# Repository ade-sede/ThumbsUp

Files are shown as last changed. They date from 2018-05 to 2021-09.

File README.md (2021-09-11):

# ThumbsUp !

A hand-worn wireless mouse made by four software developer students at school 42 Paris.
This was our free project to complete the electronics development course at 42's electronic lab.
In the traditional spirit of 42, no external libraries are allowed:
- schematic and footprints libraries were designed from scratch.
- firmware is bare metal working up from CMSIS headers.

## Main hardware components
- [RN42HID Bluetooth 2.1 Module](https://www.microchip.com/wwwproducts/en/RN42)
- [MPU9150 9-DoF sensor](https://www.olimex.com/Products/Modules/Sensors/MOD-MPU9150/open-source-hardware)
- [PIC32MX](https://lmgtfy.com/?q=PIC32+MX+Family)

A BOM is available in the `output_files/BOM` directory.

## Development tools
Altium and MPLAB IDE(xc32 compiler)

## Result
Turned out to be pretty cool and fully functional.

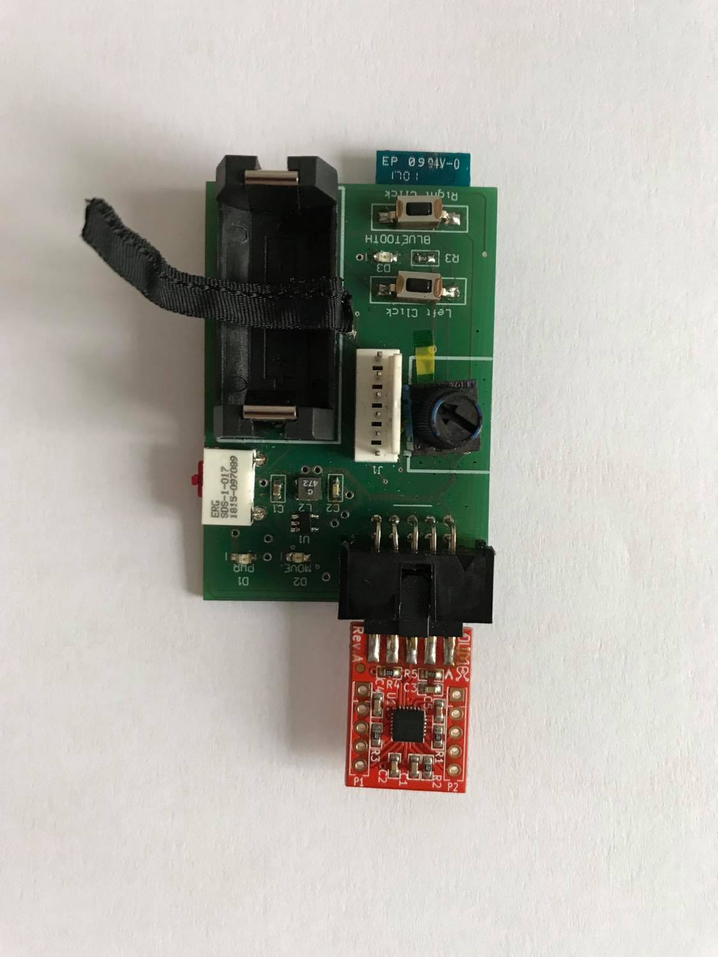
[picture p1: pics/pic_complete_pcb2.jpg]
RAW PCBA

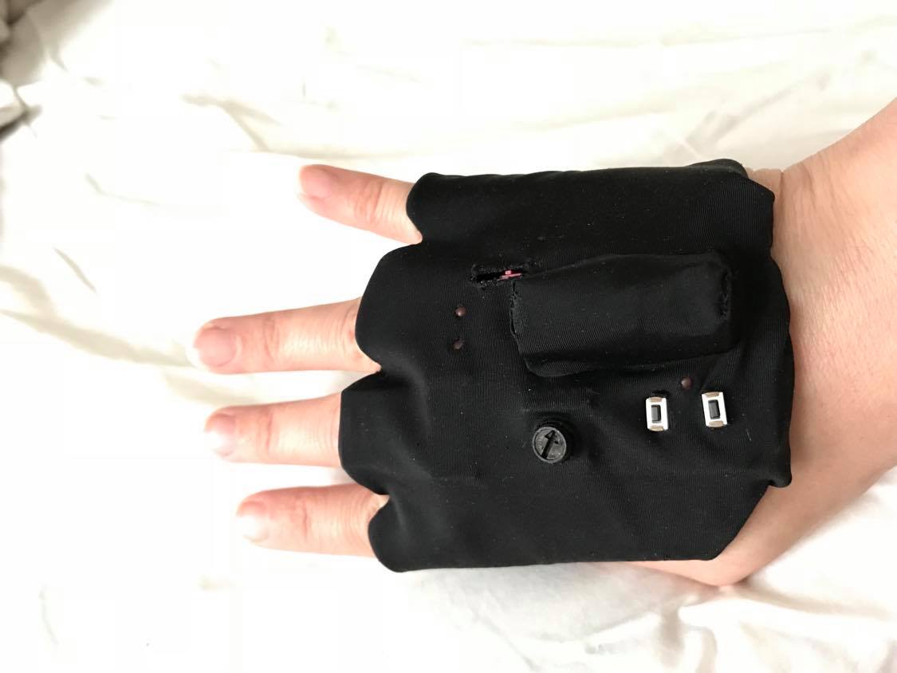
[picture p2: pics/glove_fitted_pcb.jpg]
Fitted in a glove


# Authors
- [ade-sede](https://github.com/ade-sede)
- [ssabbah](https://github.com/solalsabbah)
- [asuissa](https://github.com/asuissa)
- [alallema](https://github.com/alallema)

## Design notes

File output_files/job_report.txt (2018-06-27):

Output: Bill of Materials
Type  : BOM
From  : Variant [[No Variations]] of Project [ThumbsUp.PrjPcb]
   Generated File[Bill of Materials-ThumbsUp.xlsx]

Files Generated   : 1
Documents Printed : 0

Finished Output Generation At 4:39:21 AM On 6/27/2018

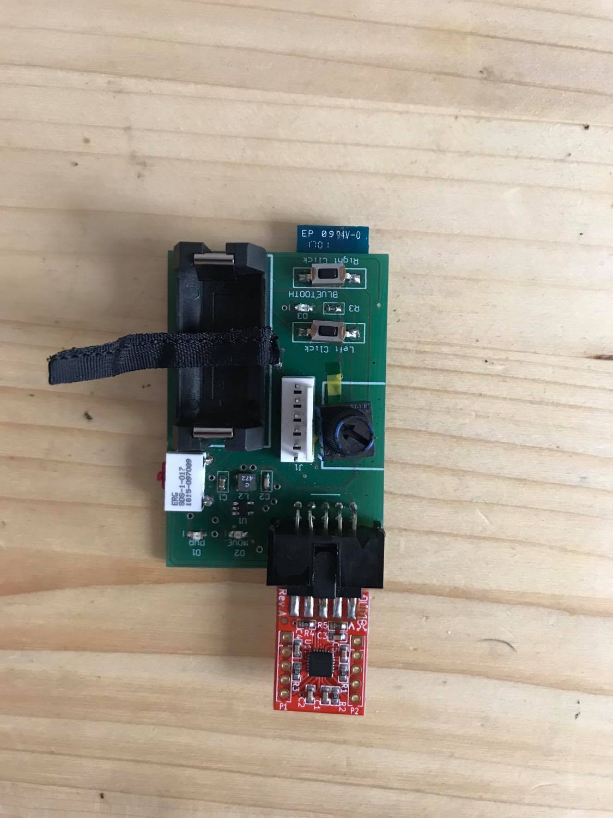
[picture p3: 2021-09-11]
pics/pic_complete_pcb1.jpg

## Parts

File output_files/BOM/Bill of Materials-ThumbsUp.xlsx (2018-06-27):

Quantity | LogicalDesignator | Fabricant | Fournisseur | RefFabricant | RefFournisseur
1 | BT2 | Keystone | Farnell | 1017 | 1888395
5 | D1, D2, D3 | Kingbright | Farnell | KPT-2012LVSECK-J3-PRV | 2610416
10 | J1 | MOLEX | Farnell | 22-27-2061 | 9731172
1 | L2 | Coilcraft | Farnell | XFL3012-472MEB | 2289189
1 | SW1 | ERG COMPONENTS | Farnell | SDS-1-017 | 1203424
10 | SW2 | ALCOSWITCH - TE CONNECTIVITY | Farnell | 1437566-3 | 2468741
1 | U1 | Microchip | Farnell | MCP1603T-330I/OS | 1439373
1 | U2 | Microchip | Farnell | PIC32MX150F128B-I/SO | 2313766

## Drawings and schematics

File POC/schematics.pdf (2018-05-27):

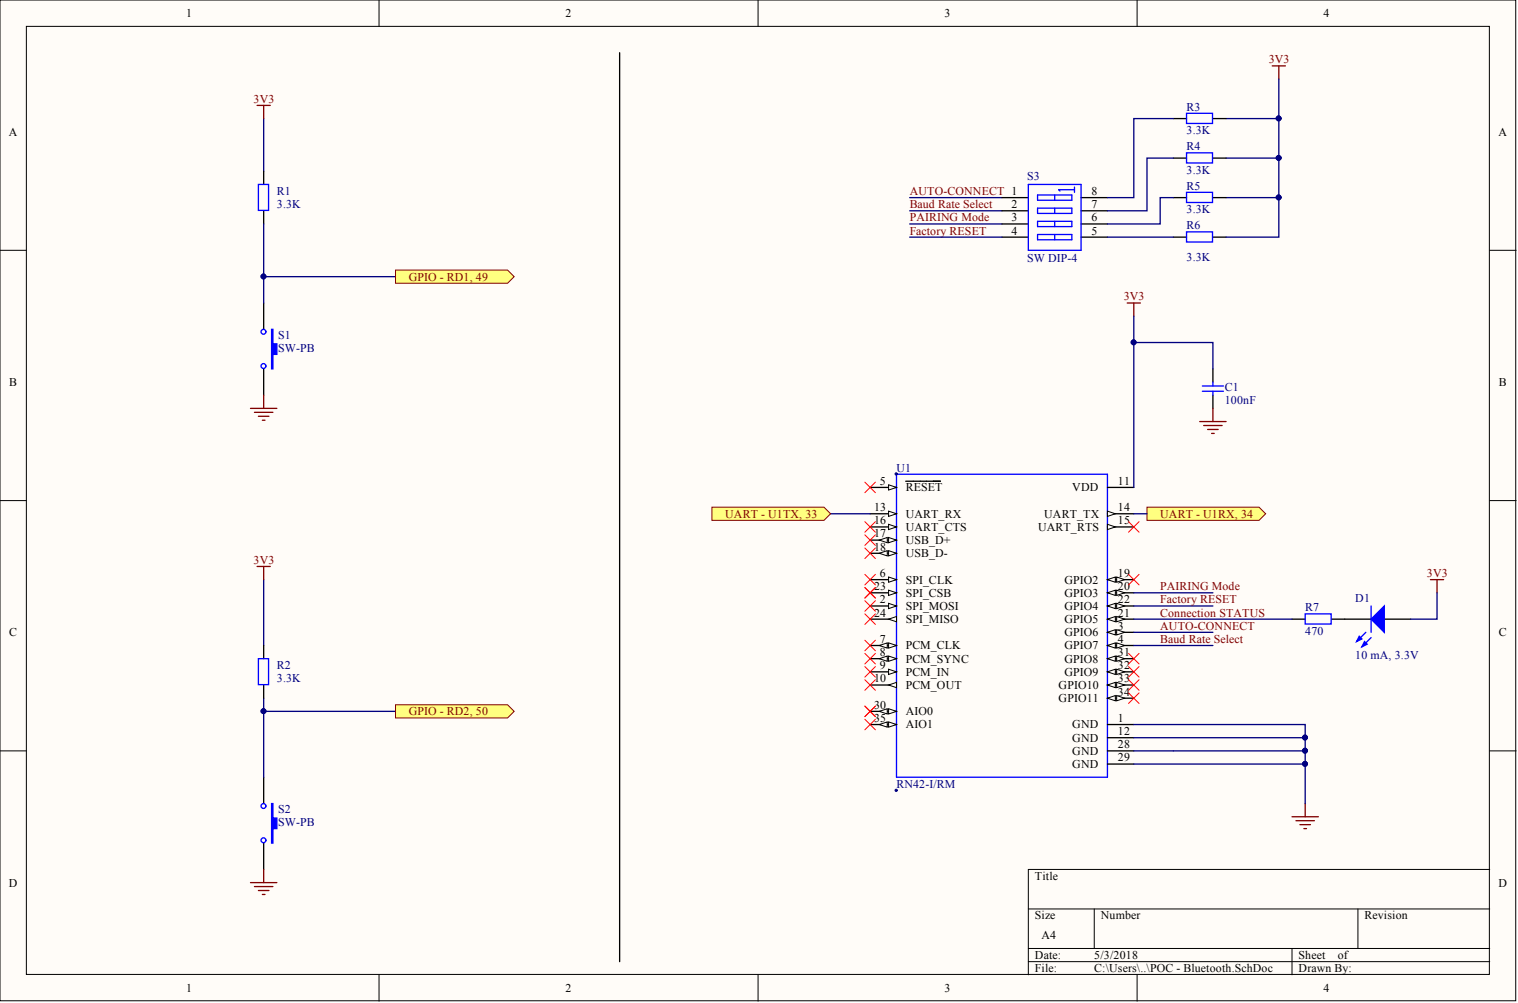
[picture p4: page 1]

7 | R6

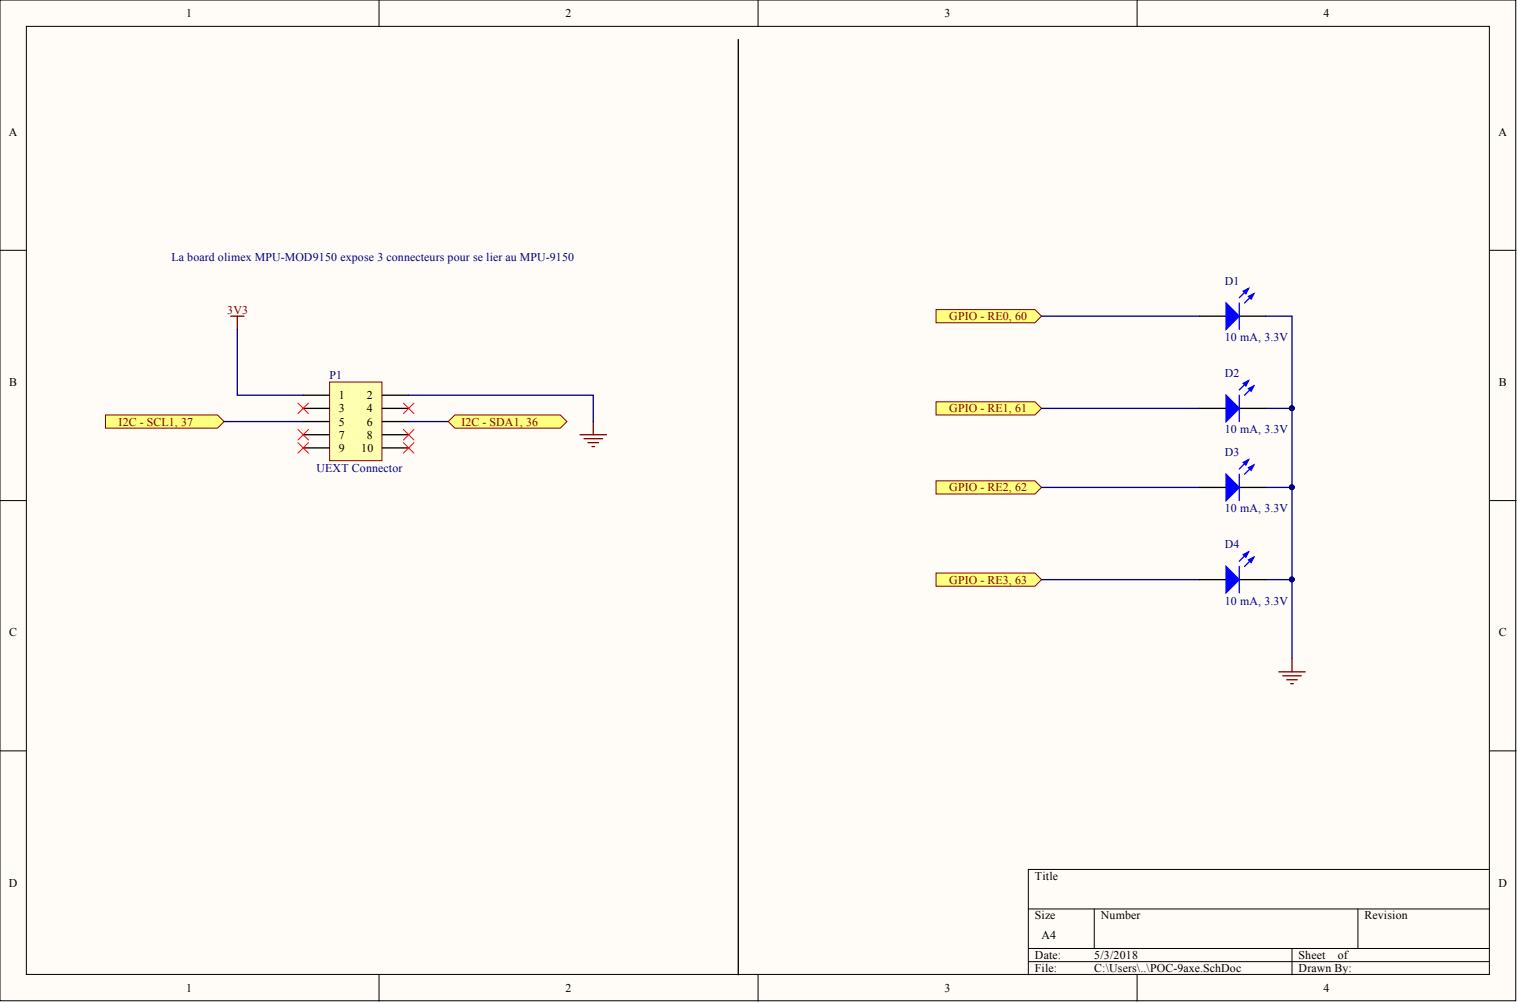
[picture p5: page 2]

La board olimex MPU-MOD9150 expose 3 connecteurs pour se lier au MPU-9150

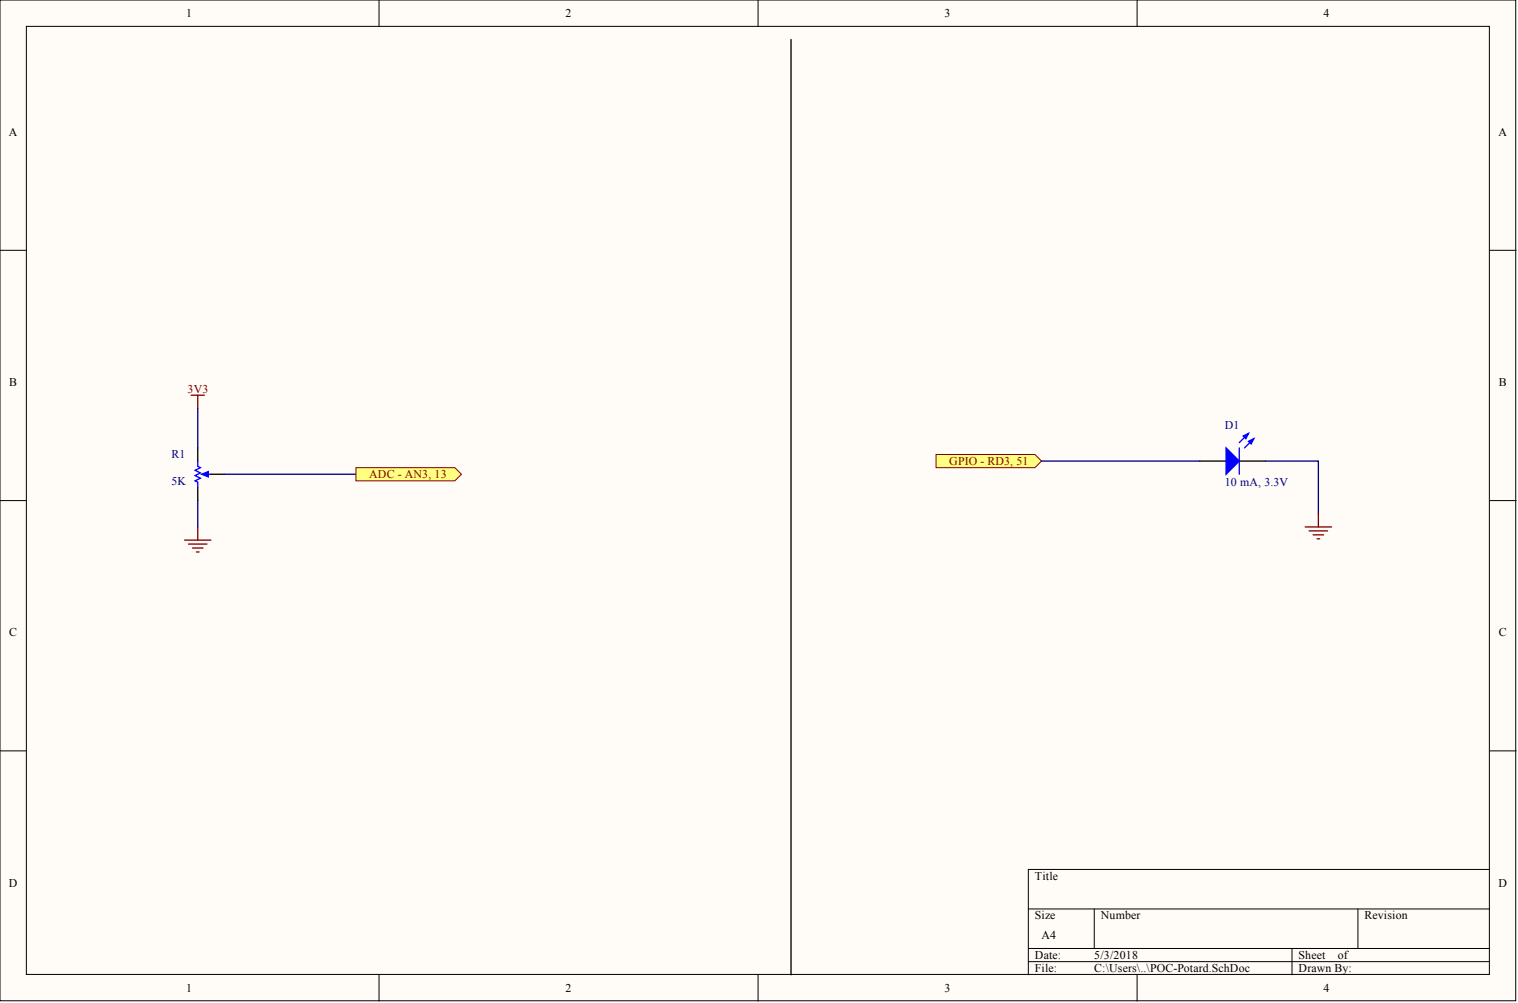
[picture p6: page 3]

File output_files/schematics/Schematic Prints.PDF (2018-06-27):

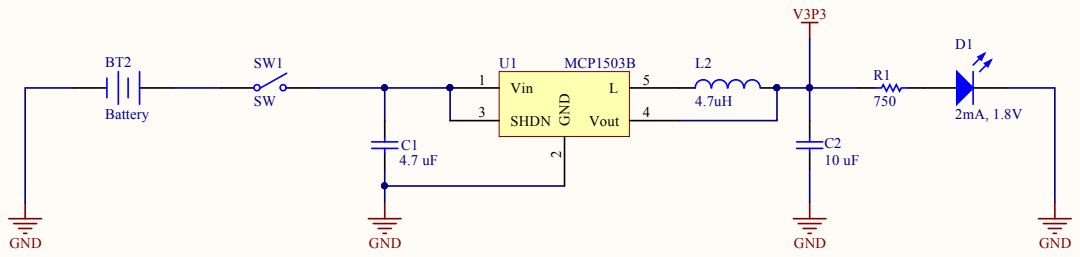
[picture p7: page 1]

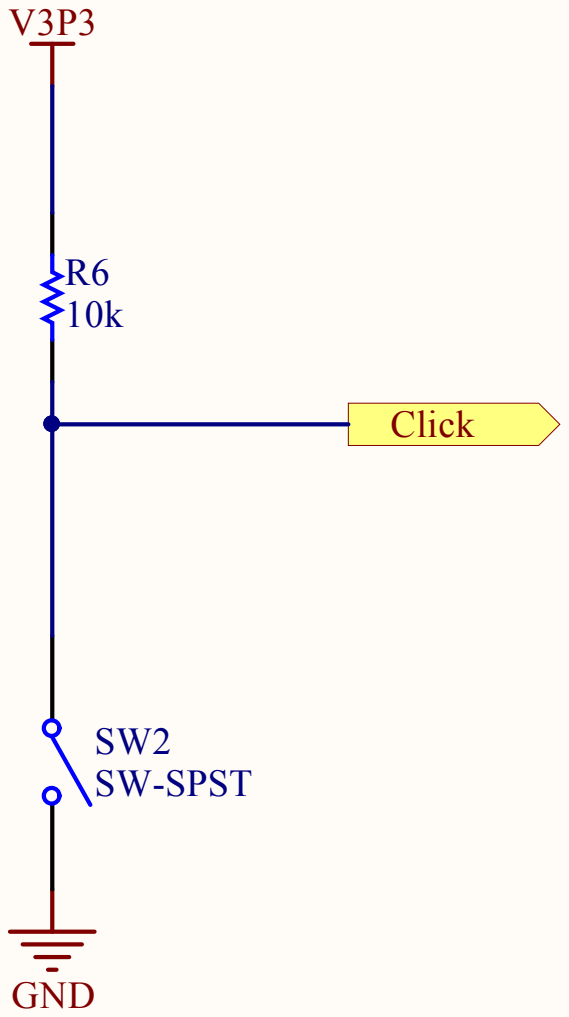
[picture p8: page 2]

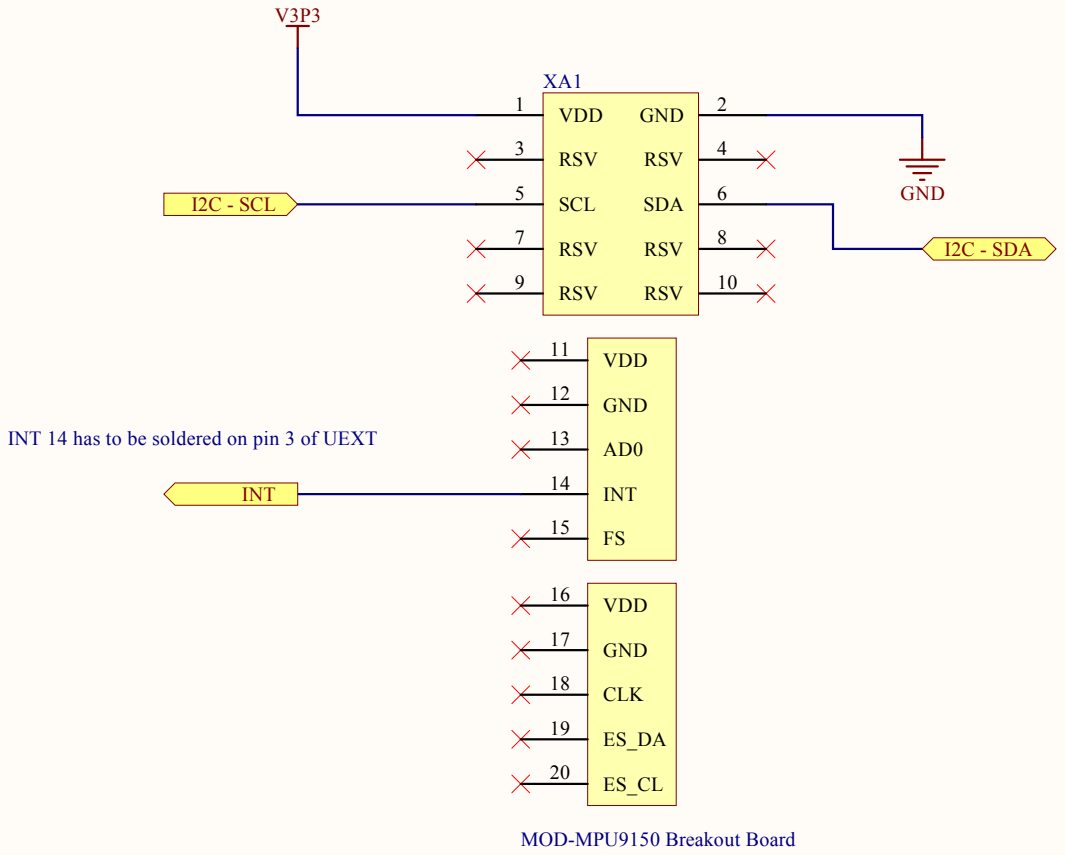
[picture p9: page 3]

INT 14 has to be soldered on pin 3 of UEXT

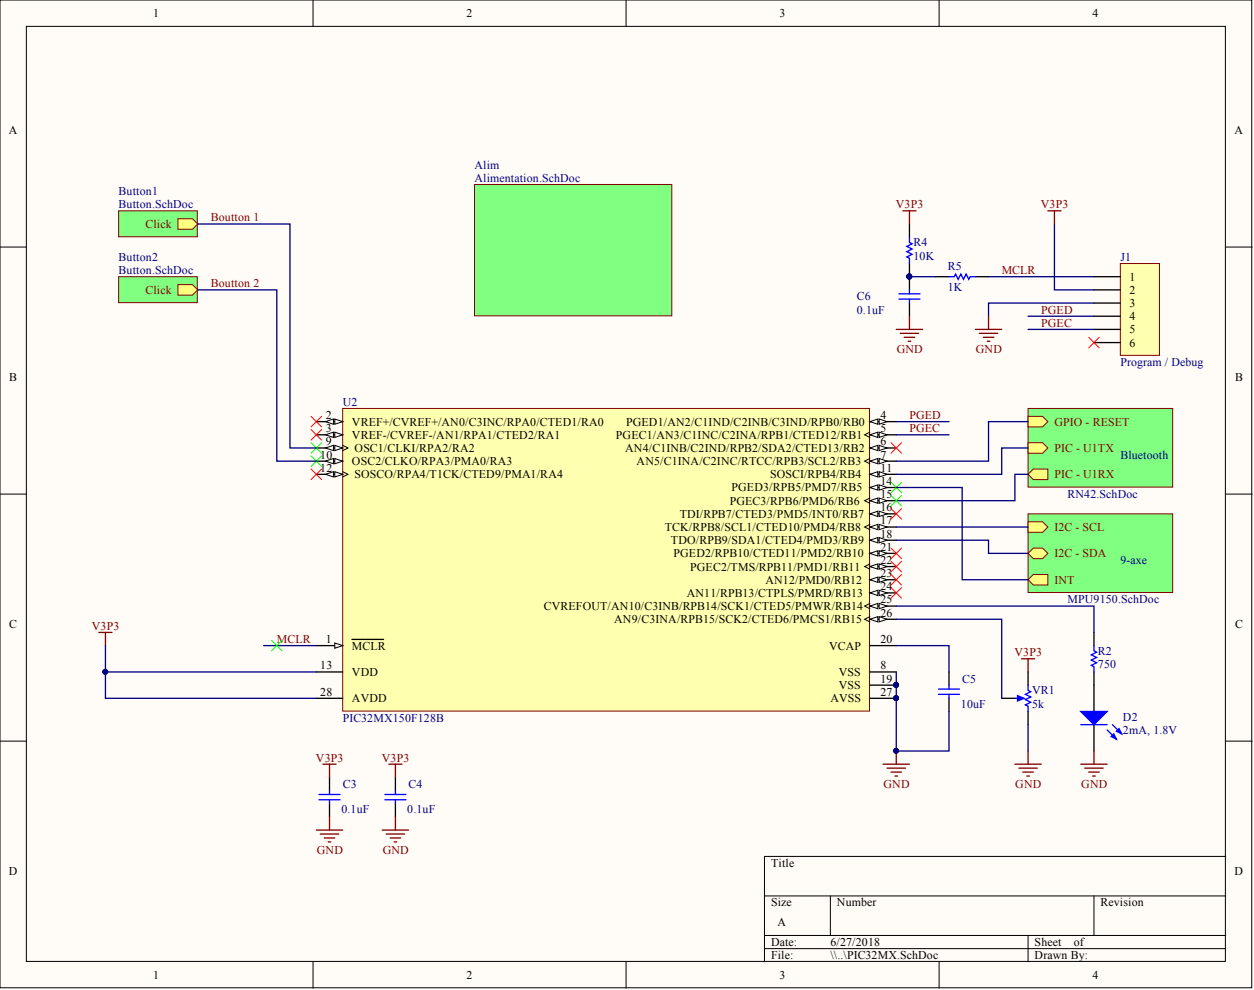
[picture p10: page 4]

1 0 | | 7

1 4
1 5
1 6
1 7 | | I2C - SCL I2C - SD A 9-ax e IN T
1 8
2 1
2 2

1 3 | 8
2 8 | 1 9

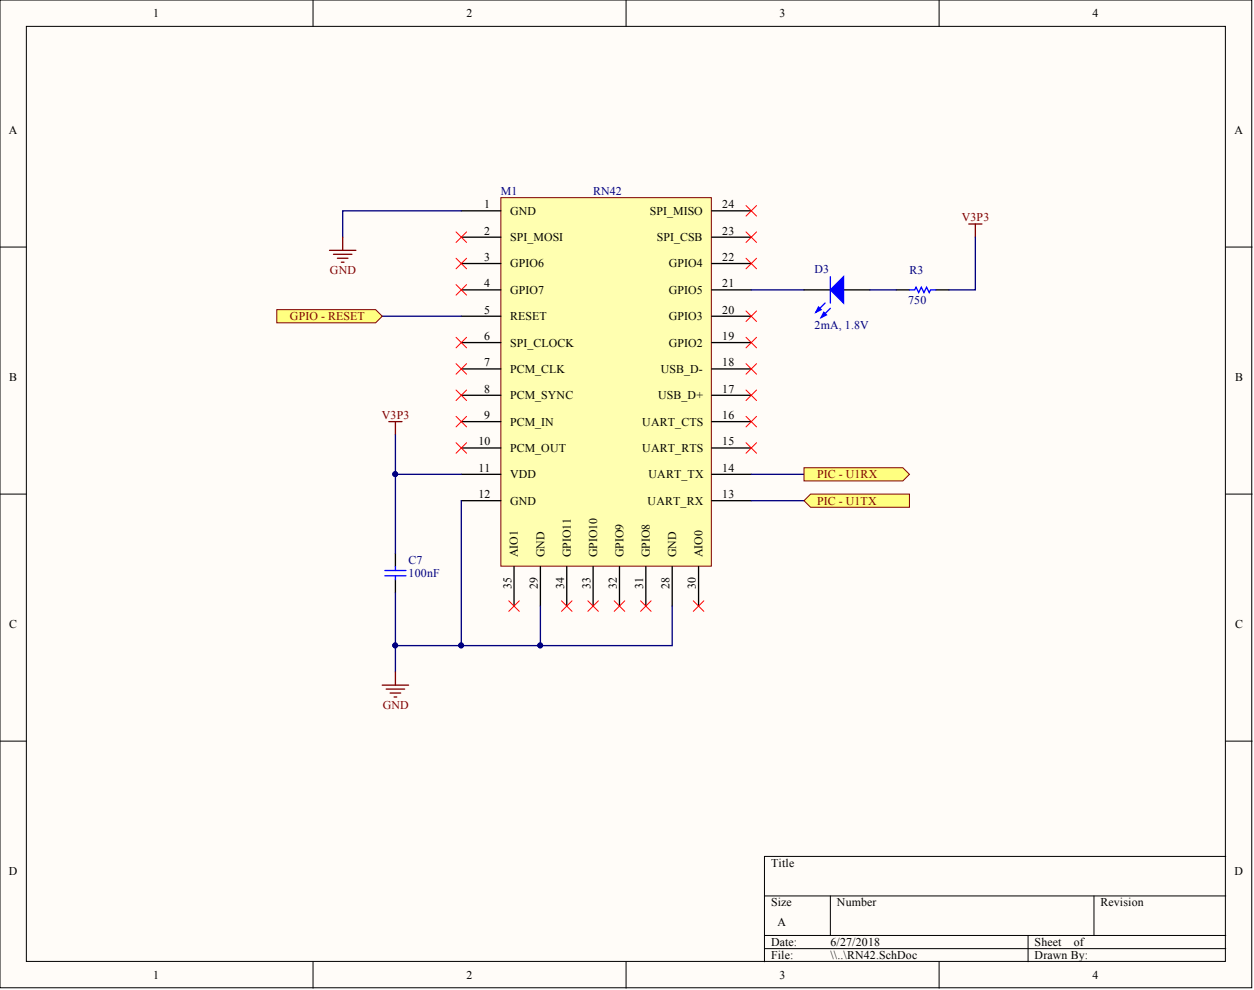
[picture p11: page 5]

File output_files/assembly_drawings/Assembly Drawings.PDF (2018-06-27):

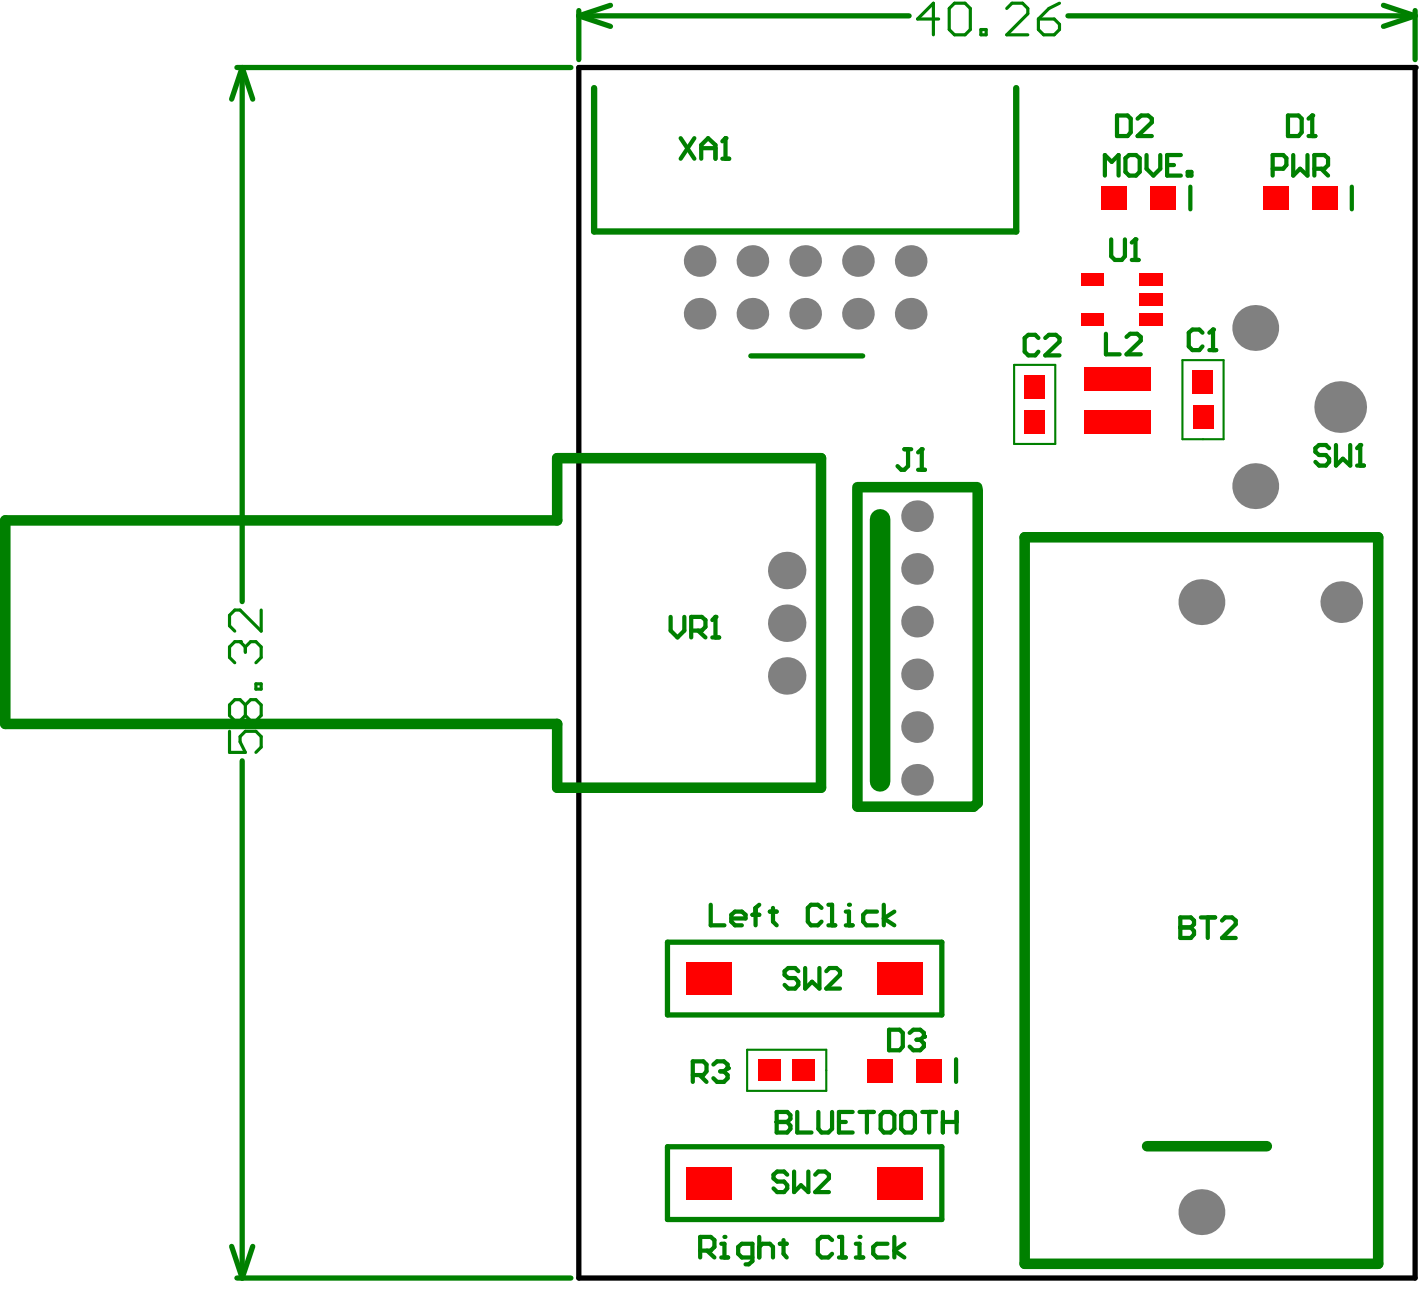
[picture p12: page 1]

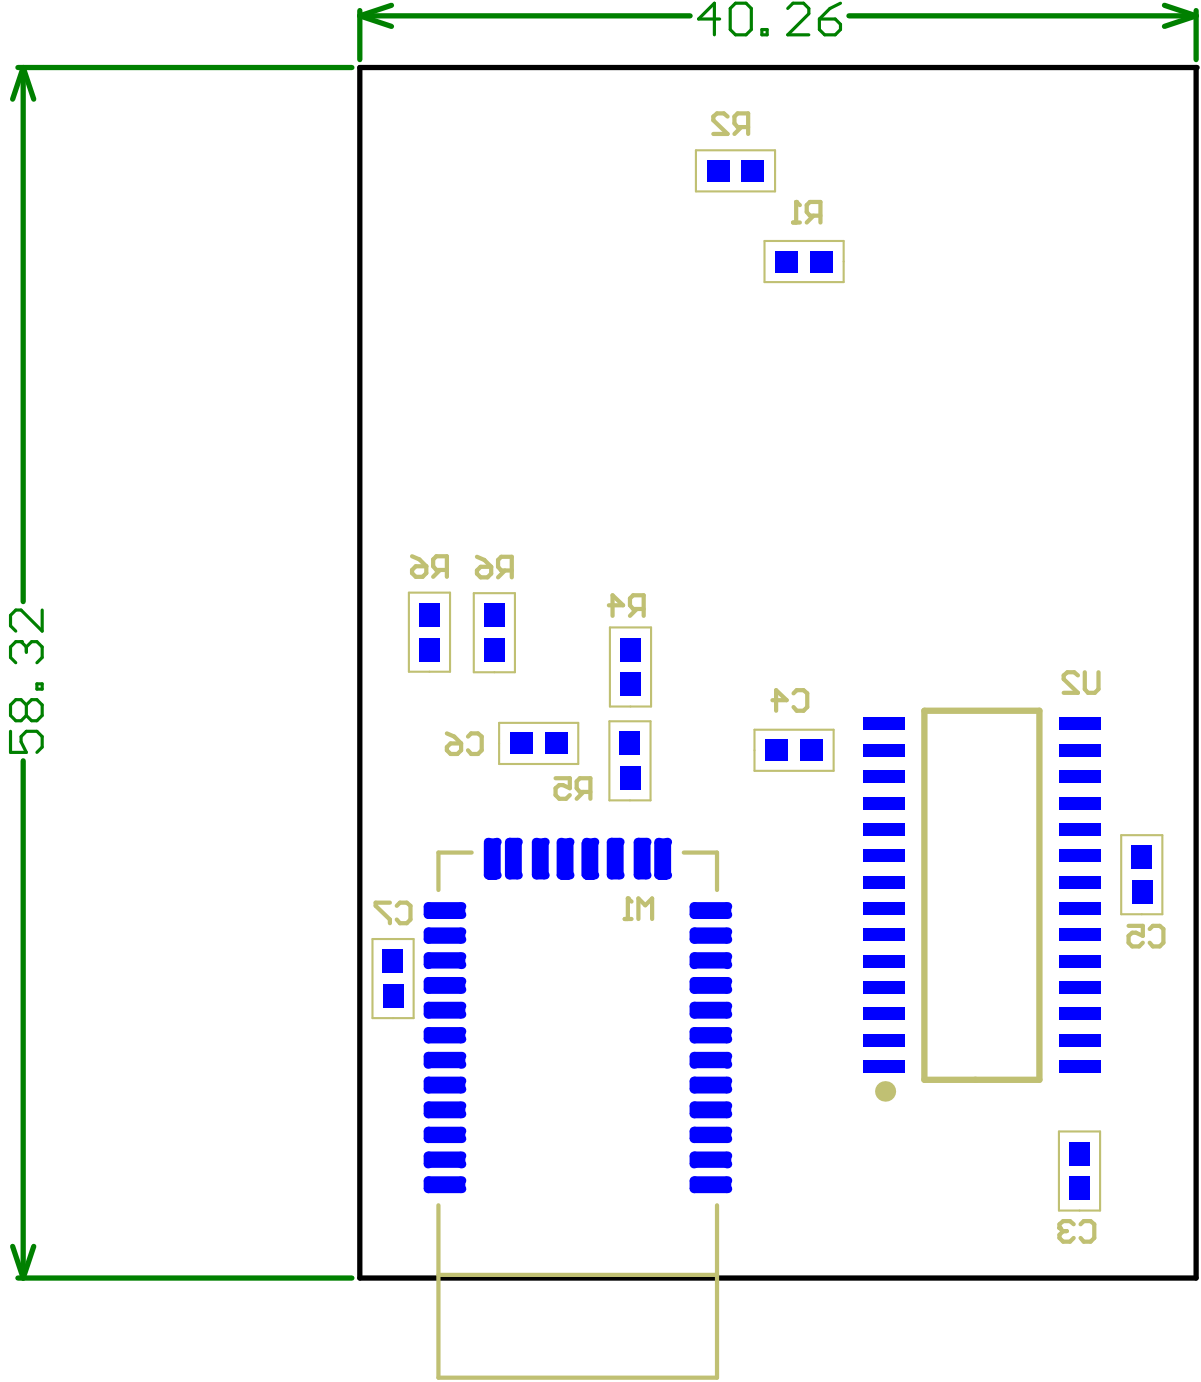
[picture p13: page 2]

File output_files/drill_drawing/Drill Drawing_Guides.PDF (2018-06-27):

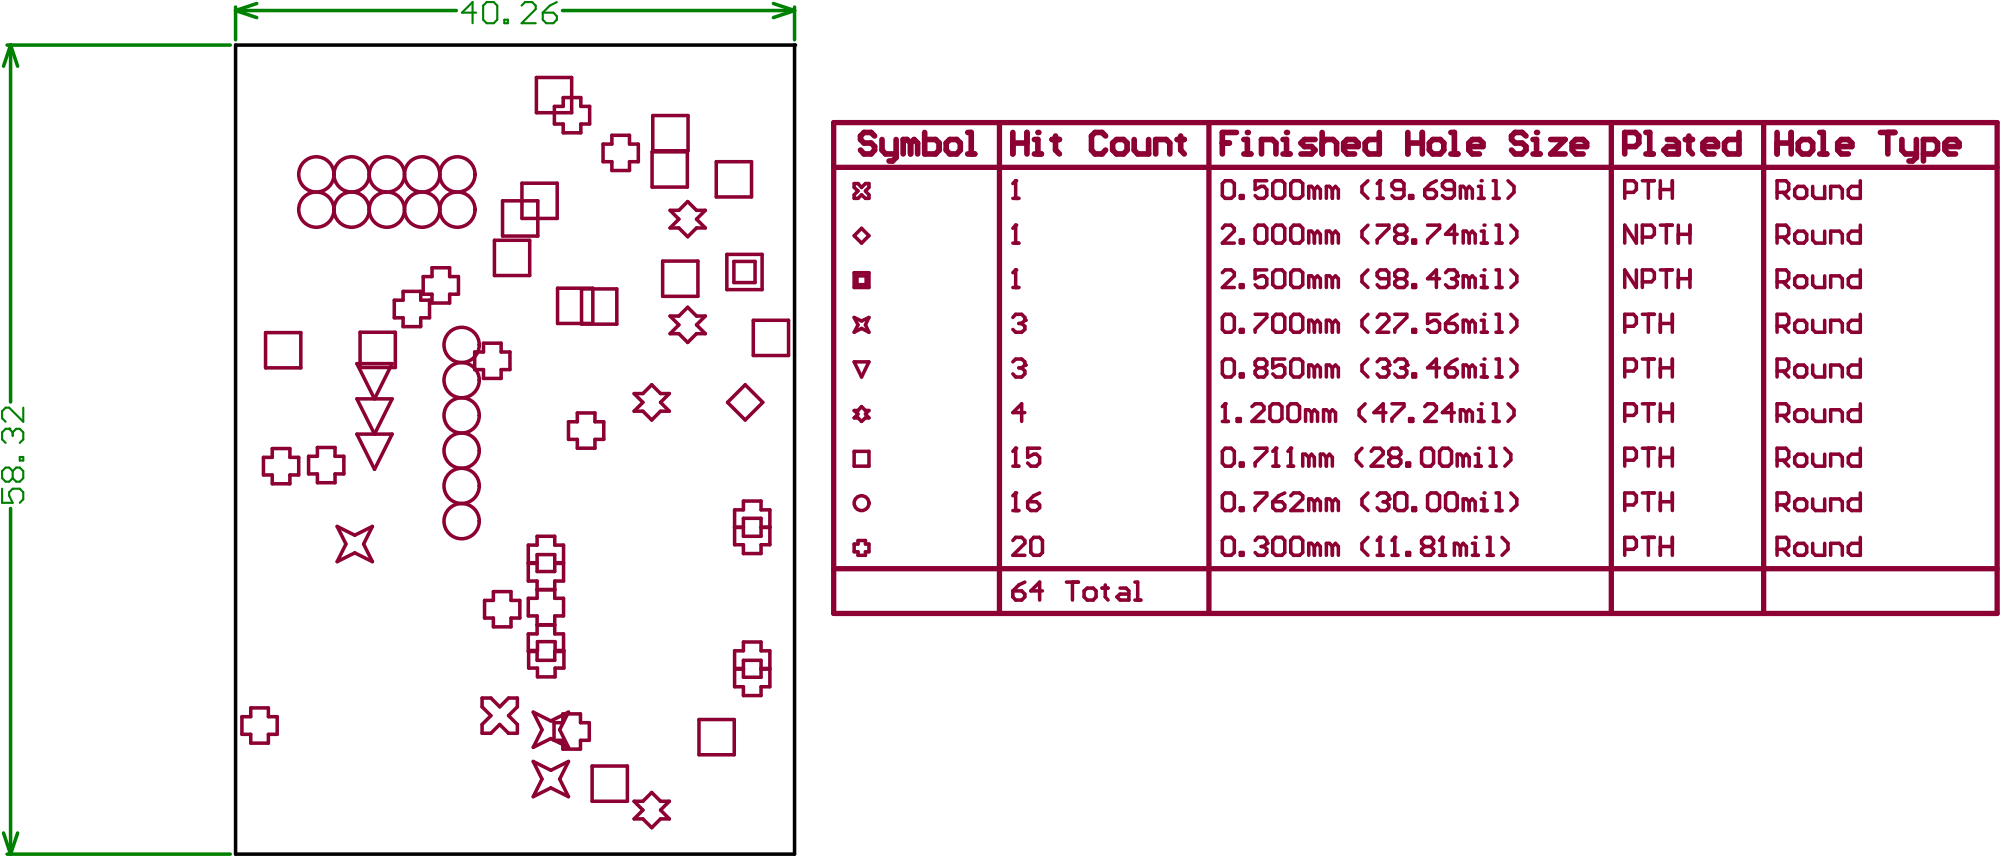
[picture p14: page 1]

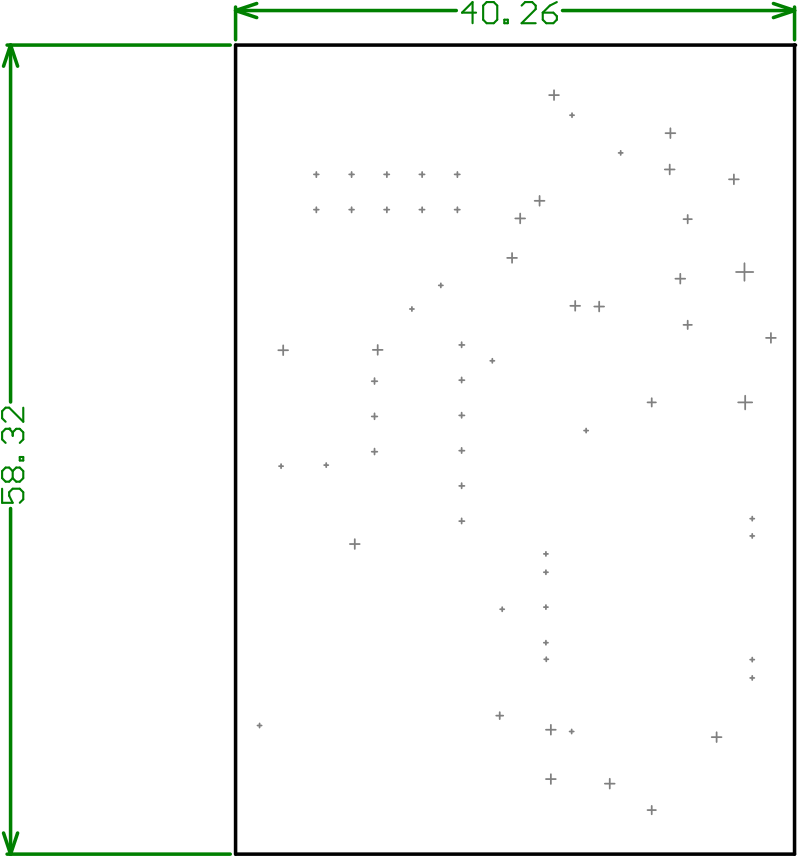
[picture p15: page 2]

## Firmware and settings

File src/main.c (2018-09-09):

#include "header.h"
#include "MPU9150.h"
#include "i2c.h"
#include "uart.h"
#include "RN42.h"
#include "movement.h"
#include "interrupt.h"

 /*
  * This variable bias represent the acceleration present on each axis, in a no-move condition
  *	They are mesured during calibration. We have to remove this bias from each measurement
  * so that it is accurate.
  */

struct s_accel g_calibration;
struct s_gravity g_accel;
struct s_gravity g_angle;
float g_accelR = 0;
float g_wheel = 0;

u8 g_button = 0;

/*
 * Function in charge of doing everything that needs to be done ONCE in order for the system to be ready
 */

void	init(void) {

        TRISBbits.TRISB14 = 0;              /* Setting up tri-state led */
        TRISAbits.TRISA2 = 1;               /* Setting up tri-state int2 input*/
	TRISAbits.TRISA3 = 1;               /* Setting up tri-state int3 input*/
        LATBbits.LATB14 = 0;                /* Turn off led on the test board */

	uart1_init((u32)RN42_BAUD_RATE + 1);/* Bluetooth */
        uart2_init((u32)RN42_BAUD_RATE + 1);/* Debug */
        init_pot();                         /* Potentiometre */
        set_interrupt();                    /* Buttons */

	i2c_config_and_start((u8)I2CBRG);   /* After this line i2c module is running with baud rate I2CBRG */
	MPU9150_write(PWR_MGMT_1, PWR_MGMT_ON_NO_TEMP);  /* Initialisation Power management -> no temp sensor */
        calibration();	/* Accelerometer and Gyroscope calibration, in a no movement condition durgin CALIBRATION_SAMPLE_NUMBER cycles */
        T4CONbits.ON = 1; /* Launch movement transmission */
}

int     main(void) {
        u32 a = 0;

        while (a < 100000)
            a++;
        memset(&g_calibration, 0, sizeof(struct s_accel));
        memset(&g_accel, 0 ,sizeof(struct s_gravity));
        memset(&g_angle, 0 ,sizeof(struct s_gravity));

	set_pps();
        init();
        uart2_putstr("Start \n\r");
	while(1){
		Nop();
	}
}

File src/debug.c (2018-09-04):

#include "MPU9150.h"
#include "uart.h"
#include "header.h"
#include "debug.h"

inline void	print_accel(struct s_accel *sample) {
	char buff[4096];

	sprintf(buff, "%d		%d		%d\n\r", sample->accelX, sample->accelY, sample->accelZ);
	uart2_putstr(buff);
}

inline void	print_report(s16 *report) {
	char buff[4096];

	sprintf(buff, "%d	%d	%d      %d\n\r", report[3], report[4], report[5], report[6]);
	uart2_putstr(buff);
}

inline void	print_arcos(struct s_gravity *sample) {
	char buff[4096];

	sprintf(buff, "%f		%f		%f\n\r", sample->accelX, sample->accelY, sample->accelZ);
	uart2_putstr(buff);
}

inline void	print_accelR(float g_accelR) {
	char buff[4096];

	sprintf(buff, "%f	\n\r", g_accelR);
	uart2_putstr(buff);
}

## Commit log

2018-05-01 First i2c test, led lights up !
2018-05-15 No interrupt version, slave stretching indefinitely
2018-05-17 I2c work
    Code en mode bloquant
2018-05-19 Test potentiometre ok value ADC1BUF0 varie de 0 a 1023
2018-05-23 Testing UART for rn42HID
2018-05-24 Un mouvement de souris est detecte avant bug
2018-05-25 Renamed repo, renamed RN42 UART file
2018-05-25 Moved everything to its own directory. Need to add schematics and altium project files too
2018-05-27 Added Altium sources
    [POC - Bluetooth.SchDoc, POC-9axe.SchDoc, POC-Potard.SchDoc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]
2018-05-27 Added Altium files for schematic library and pcb library. Contains schematics / footprint for the rn42 bluetooth module
    [PCB_Library.PcbLib, Schematics_Library.SchLib, ThumbsUp.PrjPcb]
2018-06-02 Pic32 added
    [PCB_PIC32.PcbLib, POC - Bluetooth.SchDoc, POC-9axe.SchDoc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]
2018-06-04 schematics done
2018-06-04 Schematics almost done
    [9axe.SchDoc, Bluetooth.SchDoc, PCB_PIC32.PcbLib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]
2018-06-05 Removed useless files, footprint mostly done, starting schematics
    [9axe.SchDoc, Alimentation.SchDoc, Bluetooth.SchDoc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]
2018-06-06 Add Schematics RN42, PIC - Same source V3P3 - capacitor to check - Delete SheetEntry replace by PORT
    [Alimentation.SchDoc, MPU9150.SchDoc, Main.SchDoc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]
2018-06-06 Finished schmeatics
    [Alimentation.SchDoc, Button.SchDoc, MPU9150.SchDoc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]
2018-06-06 led and switch
    [PCB_Library.PcbLib, PIC32MX.SchDoc]
2018-06-07 Schematics almost complete, most footprints up
    [Alimentation.SchDoc, Button.SchDoc, PCB_Library.PcbLib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]
2018-06-08 parameters all done except switch
    [Alimentation.SchDoc, Button.SchDoc, MPU9150.SchDoc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]
2018-06-09 add pic32 available on Farnell
    [PIC32MX.SchDoc]
2018-06-11 added footprint Header
    [PCB_Library.PcbLib, PIC32MX.SchDoc, Schematics_Library.SchLib]
2018-06-11 Fixed most of the footprints Pcb component placement is done, alignement and routing are still left.
    footprints to fix: Power on switch
    [Alimentation.SchDoc, MPU9150.SchDoc, PCB.PcbDoc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]
2018-06-14 Ajout Avi, PCB faites, a retoucher
    [PCB - Copy.PcbDoc, PCB - ancienne.PcbDoc, PCB1.PcbDoc]
2018-06-15 Safety commit, work in progress, this commit will disappear during a manul fast forward" "
    [Alimentation.SchDoc, Button.SchDoc, PCB - Copy.PcbDoc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]
2018-06-19 Small PCB almost complete
    [PCB_small_version.PcbDoc, Schematics_Library.SchLib]
2018-06-21 Routing almost complete
    [PCB_small_version.PcbDoc]
2018-06-21 Re-designed alim circuit to shorten some tracks. Added and configured output job
    [PCB_small_version.PcbDoc, ThumbsUp.PrjPcb]
2018-06-21 Fixed output job configuration -> Added colors, changed unit to milimeters
    [Bill of Materials-ThumbsUp.xlsx]
2018-06-21 Fixed holes on footprints
    [PCB_Library.PcbLib, PCB_small_version.PcbDoc, ThumbsUp.PrjPcb]
2018-06-24 GND trace et regu deplace en top
    [PCB_small_version.PcbDoc]
2018-06-25 ICSP + Serigraphie done
    [Bill of Materials-ThumbsUp.xlsx, PCB_Library.PcbLib, PCB_small_version.PcbDoc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]
2018-06-27 Completed first complete version. No DRC errors, compiles, output job in order
    [Bill of Materials-ThumbsUp.xlsx, PCB.PcbDoc, PCB_Library.PcbLib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]
2018-06-27 Corrected footprints, handmade BOM, complete gerber files
    [Alimentation.SchDoc, Bill of Materials-ThumbsUp.xlsx, Button.SchDoc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]
2018-07-03 ajout dossier soft + fonction calcul de deplacement
2018-07-09 i2c et uart ok - pragma a verif toujours sur PRIPLL
2018-07-11 uart ic2 ok - test putnbr_uart
2018-07-11 oups fix UART_transmitnbr
2018-07-17 Writing code without testing ... Rename i2c_config_rester to config_MPU9150_register
2018-07-17 Rename I2C.c in lower case
2018-07-17 Removed a lot of useless i2c function. Renamed functions that are specific to the MPU9150 to MPU9150_* and changed i2c.c to MPU9150.c
2018-07-18 Now working with unsigned types. Created a struct for the velocity. Started the function to compute movement : sampling and cleanup done
2018-07-18 Thecurrent accel used to compute is now seen as a medium of the current measurement and the old one
2018-07-20 Rename all UART to lowercase uart, following by the corespind uart number (uart1, uart2, etc etc)
2018-07-20 fixed compiles errors from reference to old UART functions
    [MPU9150.c, main.c, uart1.c]
2018-07-23 Test Bluetooth in progress - Not Working
    [main.c, uart1.c]
2018-07-24 Crash windows secure save - Mouse movement work and MPU9150 too
    [main.c, uart1.c, uart2.c]
2018-07-24 Not working with null movement
    [main.c]
2018-07-31 interrupt for button et report to test
2018-08-01 fix mistake and start timer
    [main.c]
2018-08-01 test interrupts
2018-08-02 interrupt ok with D8 button working
2018-08-05 timer turn led off
2018-08-13 button in progress interrupt segfault when button is overused
2018-08-16 test handle debounce button with interrupt
2018-08-17 interrupt bouton ok potentiometre ok
2018-08-20 add doubleclick with Timer4 without testing
2018-08-20 add retrieve gyroscope mesurement without testing
2018-08-20 button push ok test gyro
2018-08-20 starting sample for Gyro
2018-08-22 modify button in global variable, add gyroscope calibration, check gyroscope movement to re calibration accelerometre in case
2018-08-23 compil ok gyro struct a clean + master_sens bloquante a changer
2018-08-23 comments add on I2C
2018-08-24 fix gyro struct error and add some define and comments
    [MPU9150.c, main.c]
2018-08-24 fix wheel problem still memory problem undefine ... clean and clean gyro function. Calibration during movement doesn't work
    [MPU9150.c, debug.c, main.c]
2018-08-25 add 9 clock to reset i2c module + add global variable who keep gyroscope value less calibration number
    [MPU9150.c, debug.c, i2c_utils.c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]
2018-08-27 tranforming the data of accelerometer in m/s2
2018-08-27 ajout calcul de temps
2018-08-30 starting non blocking i2c
2018-08-31 begining of software on pcb pic
2018-09-01 Uart ok potentiometre ok
2018-09-02 i2c and interrupt ok
2018-09-03 test interrupt button release ok
2018-09-03 cleaning movement and add modif button release
2018-09-03 uart2 + code plus propre
2018-09-03 bug uart
2018-09-04 wheel OK, pcb complete, good job
2018-09-04 adjustement wheel
2018-09-09 turn on led on calibration correcting axis of movement
    [main.c]
2021-09-11 Cleaned up the project, added pics to the readme
    [Bill of Materials-ThumbsUp.xlsx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]
